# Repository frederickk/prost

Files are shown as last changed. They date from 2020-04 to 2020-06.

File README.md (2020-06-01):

# 🍻 Prost!

v.0.1.2

### Prost! uses Arduino Pro Micros as intermediary to allow Midi host to Midi host communication.

<sub>(Pros + Host) x 2 = [Prost!](https://dictionary.cambridge.org/dictionary/german-english/prost) SWDIT?</sub>

Here's a brief [demo video](https://www.youtube.com/watch?v=BwLtm9UBdX8) with [Ableton Live](https://www.ableton.com/), an [Organelle](https://www.critterandguitari.com/organelle), and [Norns/Fates](https://llllllll.co/t/fates-a-diy-norns-dac-board-for-raspberry-pi/). 

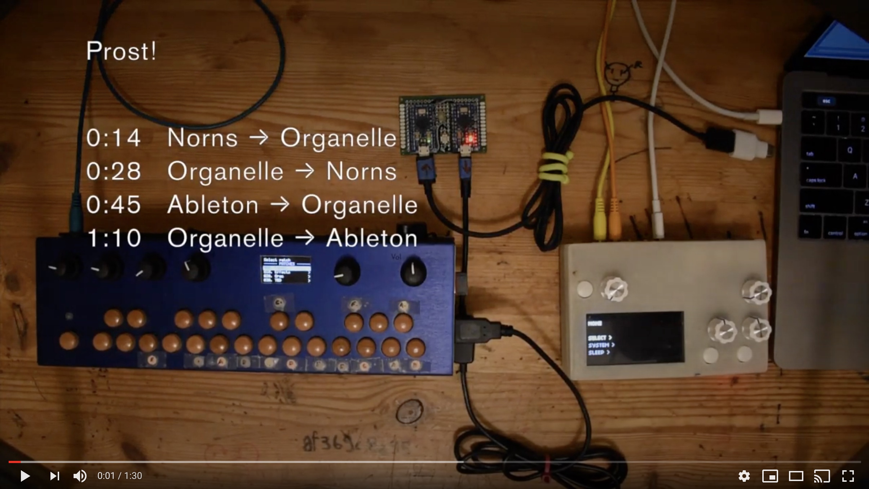
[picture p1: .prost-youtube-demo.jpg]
Prost! video demo (https://www.youtube.com/watch?v=BwLtm9UBdX8&feature=youtu.be)


------
## 💾 Firmware

**Download**

```bash 
$ git clone https://github.com/frederickk/prost.git
```

**Dependencies**

Prost! requires 2 dependencies to build and upload. 

- Install [PlatformIO](https://platformio.org/platformio-ide) this is required to build and flash the Arduinos. You can either install the [CLI](https://platformio.org/install/cli) or the [IDE](https://platformio.org/platformio-ide).
- [USBMIDI](https://github.com/BlokasLabs/usbmidi/) is required for transmitting Midi data over USB, fortunately PlatformIO makes dependency bundling easy.

Before building and flashing be sure to install dependencies.

```bash
  # Install dependencies
  pio lib --storage-dir ./lib install 5841   
```

**Build and Flash**

For 5V / 16MHz boards use:

```bash
  # Build and flash firmware
  pio run -e sparkfun_promicro16 -t upload
```

If using 3.3V / 8MHz boards use:

```bash
  # Build and flash firmware
  pio run -e sparkfun_promicro8 -t upload
```

Be sure to flash both boards 😃.

------
## 🎛️ Hardware

Prost! uses 2 [Pro Micro](https://www.sparkfun.com/products/12587) boards (or any compatible board or clone with an [Atmel 32u4 chip](https://www.amazon.com/s?k=32U4&i=electronics&ref=nb_sb_noss_2)) connected serially (TX/RX) in order to pass USBMidi data. Other boards may work (e.g. Teensy), but I only tested with Pro Micros.

I've created a PCB which reduces the footprint of the device to be only slightly larger than a Pro Micro board itself (38mm x 35mm / 1.25" x 1.375"). Below I've soldered 2 header pins in order to test different boards, but you could solder the boards directly to further reduce the overall thickness (unless you opt to solder on the 3.5mm analog sync jack).

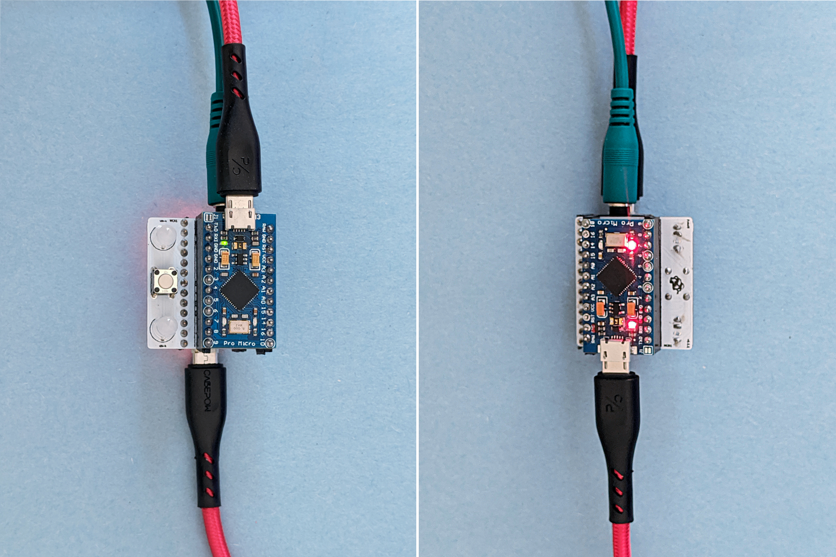
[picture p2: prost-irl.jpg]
Prost! IRL


**Board**

A custom PCB is also available. if there's enough interest I would be willing to produce these in bulk and sell either bare PCB's or populated with components. For now you can order them yourself from [JLCPCB](https://jlcpcb.com/quote/gerberview/d1965d72-c9b5-4de7-8c59-df7167853c5e_1_0_6_0_0.html).

Although, the board is designed first and foremost for Pro Micros it can accomodate a number of other boards. Be mindful to align the marked `TX` and `RX` pins on the Prost! PCB with those on your board. 

| Board | RX | TX | Voltage | Notes |
| --- | -- | -- | --- | ----- |
| [Pro Micro](https://learn.sparkfun.com/tutorials/pro-micro--fio-v3-hookup-guide/hardware-overview-pro-micro) | 0  | 1  | 3.3 or 5 | |
| [Teensy 1.0, ++](https://www.pjrc.com/teensy/td_uart.html) | 2  | 3  | 3.3 or 5 | |
| [Teensy LC, 3.0, 3.1, 3.2, 3.5, 3.6, 4.0](https://www.pjrc.com/teensy/td_uart.html)  | 0  | 1  | 3.3 or 5 | |
| [Arduino Micro](https://content.arduino.cc/assets/Pinout-Micro_latest.pdf) | 20 | 21 | 3.3 or 5 | |
| [Adafruit Feather 32u4, Bluefruit](https://learn.adafruit.com/adafruit-feather-32u4-basic-proto/pinouts) | 0  | 1  | 3.3 | Board must be mounted upside down |
| [Adafruit ItsyBitsy 32u4](https://learn.adafruit.com/introducting-itsy-bitsy-32u4/pinouts) | 0  | 1  | 3 or 5 |

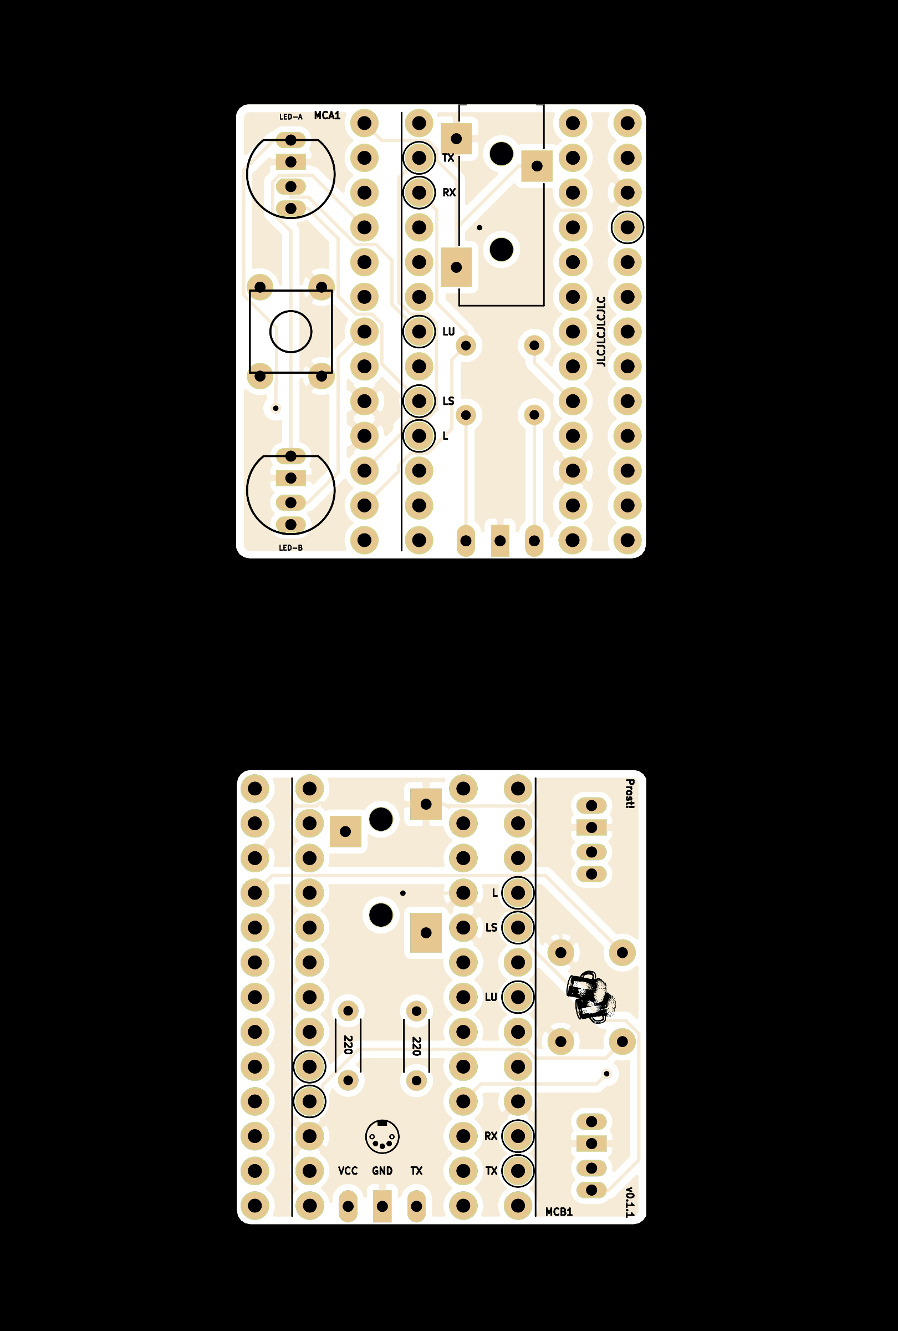
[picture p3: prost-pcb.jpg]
Prost! PCB


**BOM**

| Qty. | Part No. | Item |
| ---- | --- | ---- |
| **2** | | **5V/3.3V [Pro Micro](https://www.sparkfun.com/products/12587)** |
| **1** | **[1825910-6](https://octopart.com/1825910-6-te+connectivity-42270338?r=sp)** | **6mm Momentary push button** |
| 2 | [WP154A4SUREQBFZGW](https://octopart.com/wp154a4sureqbfzgw-kingbright-12087875?r=sp) | 5mm RGB LED (optional) |
| 4 | | 1 x 10 female header (optional) |

Syncing with DIN Midi devices is also possible. Look for the 5-pin Midi graphic on the board and you'll find pin breakouts to connect a 5-pin Midi connector. Be sure to obtain 2 220 ohm resistors as well.

| Qty. | Part No. | Item |
| ---- | --- | ---- |
| 1 | [1134](https://octopart.com/1134-adafruit+industries-32978196?r=sp) | 5-pin MIDI connector (optional) |
| 2 | [220R](https://octopart.com/search?q=220+ohm+resistor&currency=USD&specs=0&category_id=6312) | 220 ohm THT resistors (optional) |

Prost! also supports analog sync, which takes the USB Midi clock signal and converts it to 3.3V or 5V (depending on voltage of Pro Micro) pulse; for Volcas, Pocket Operators, etc. There's room on the board for an [SMD 3.5mm/.125" audio jack](https://octopart.com/search?q=CUI+SJ-3523-SMT&currency=USD&specs=0) or pads to solder a jack type of your choice.

| Qty. | Part No. | Item |
| ---- | --- | ---- |
| 1 | [CUI SJ-3523-SMT](https://octopart.com/search?q=CUI+SJ-3523-SMT&currency=USD&specs=0) | SMD 3.54mm/.125" audio jack (optional) |

**Wiring**

The diagram below shows how to connect the the 2 Pro Micros TX and RX pins. A push button is wired to [reset the bootloader](https://learn.sparkfun.com/tutorials/pro-micro--fio-v3-hookup-guide/all#ts-reset) (for flashing if/as needed). The optional LEDs signal when Midi and Serial commands are being received and sent.

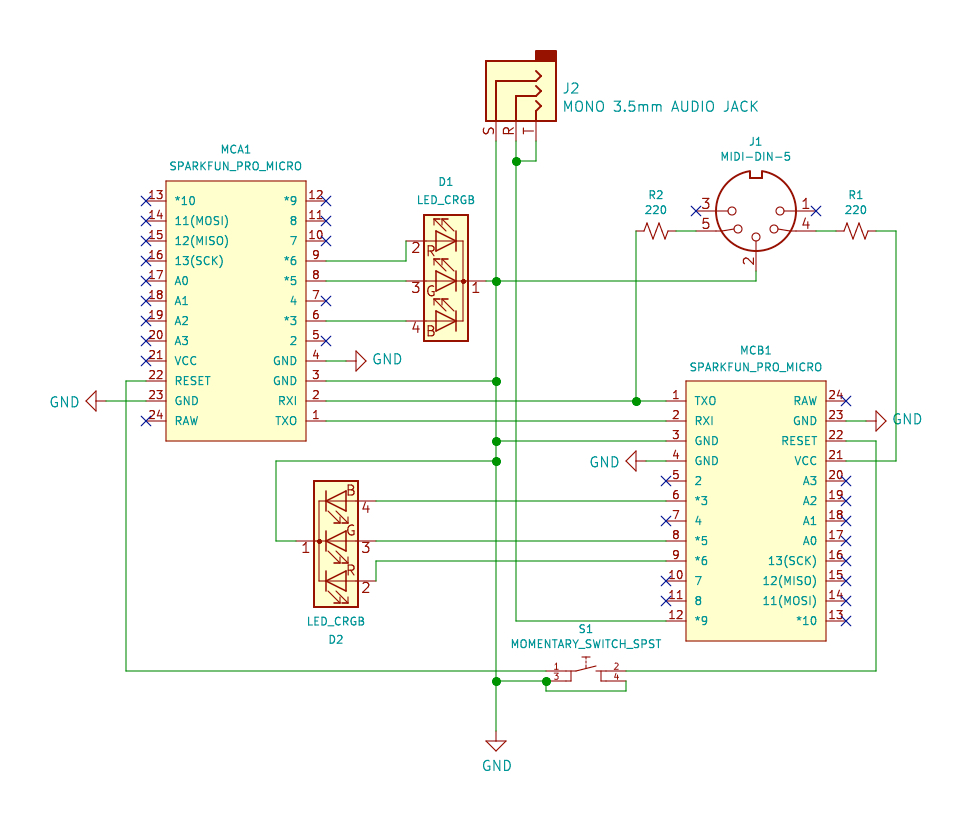
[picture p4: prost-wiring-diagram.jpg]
Prost! PCB


------
## 📜 License

[MIT](https://opensource.org/licenses/MIT)

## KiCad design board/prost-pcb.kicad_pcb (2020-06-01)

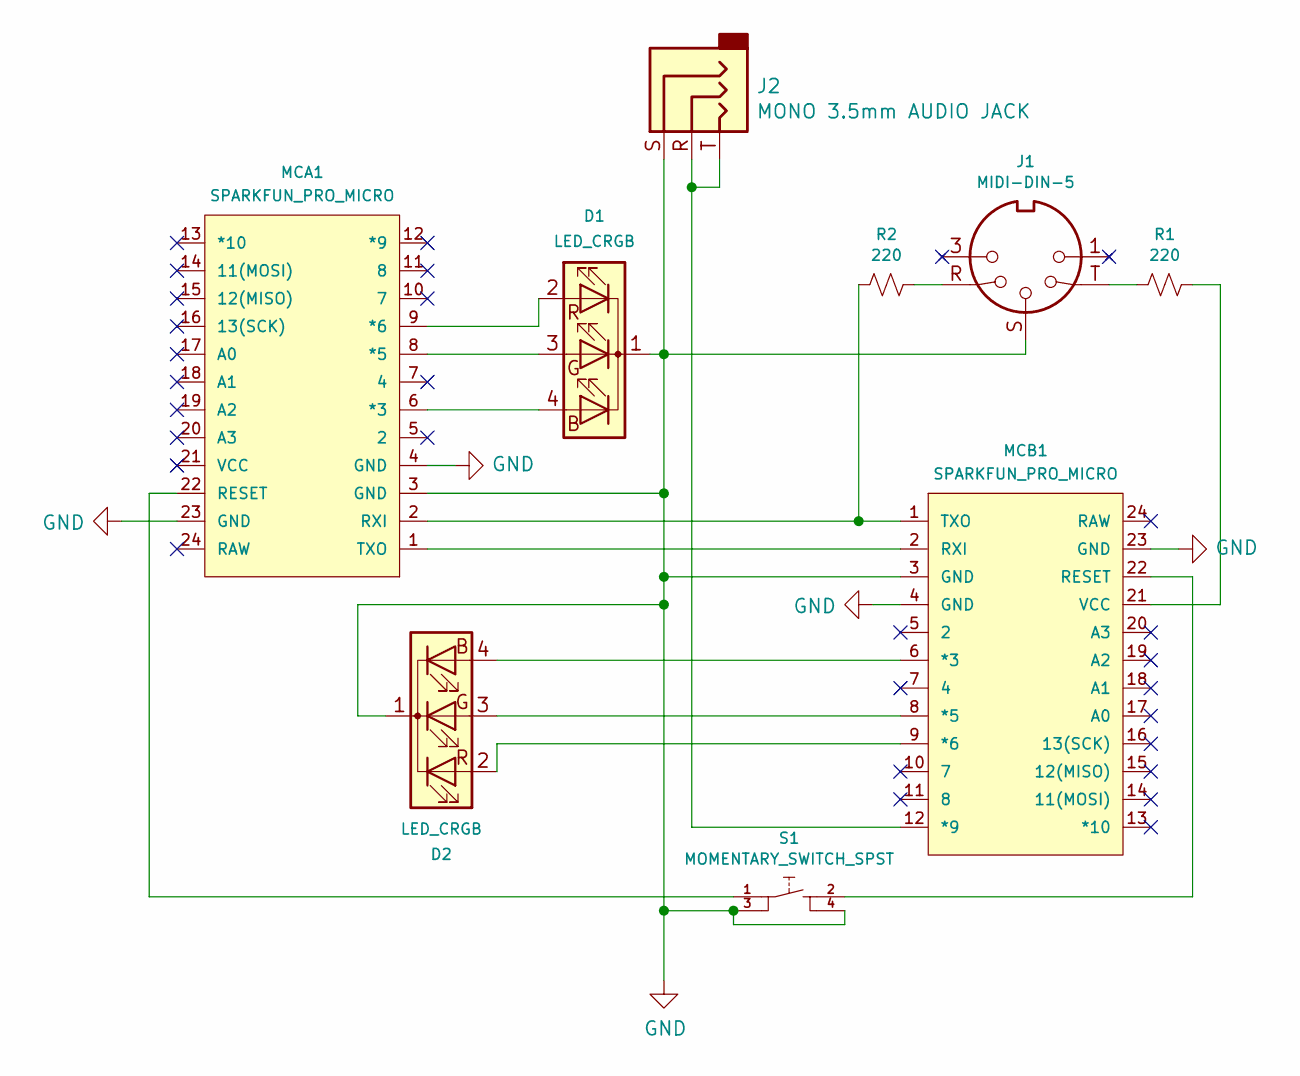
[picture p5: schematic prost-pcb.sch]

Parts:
D1, D2: LED_CRGB; LED_5MM_RGB
J1: MIDI-DIN-5; Jack_3.5mm_CUI_SJ-3523-SMT_Horizontal
J2: MONO 3.5mm AUDIO JACK; Jack_3.5mm_CUI_SJ-3523-SMT_Horizontal
MCA1: SPARKFUN_PRO_MICRO
MCB1: SPARKFUN_PRO_MICRO
R1, R2: 220; R_Axial_DIN0204_L3.6mm_D1.6mm_P5.08mm_Horizontal
S1: MOMENTARY_SWITCH_SPST; MINI_PUSHBUTTON_SWITCH

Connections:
GND: D1.1 (K), D2.1 (K), J1.S, J2.S, MCA1.3 (GND), MCA1.4 (GND), MCA1.23 (GND), MCB1.3 (GND), MCB1.4 (GND), MCB1.23 (GND), S1.3, S1.4
unnamed: D1.2 (RA), MCA1.9 (*6)
unnamed: D1.3 (GA), MCA1.8 (*5)
unnamed: D1.4 (BA), MCA1.6 (*3)
unnamed: D2.2 (RA), MCB1.9 (*6)
unnamed: D2.3 (GA), MCB1.8 (*5)
unnamed: D2.4 (BA), MCB1.6 (*3)
unnamed: J1.R, R2.1
unnamed: J1.T, R1.2
unnamed: J2.R, J2.T, MCB1.12 (*9)
unnamed: MCA1.1 (TXO), MCB1.2 (RXI)
unnamed: MCA1.2 (RXI), MCB1.1 (TXO), R2.2
unnamed: MCA1.22 (RESET), S1.1
unnamed: MCB1.21 (VCC), R1.1
unnamed: MCB1.22 (RESET), S1.2

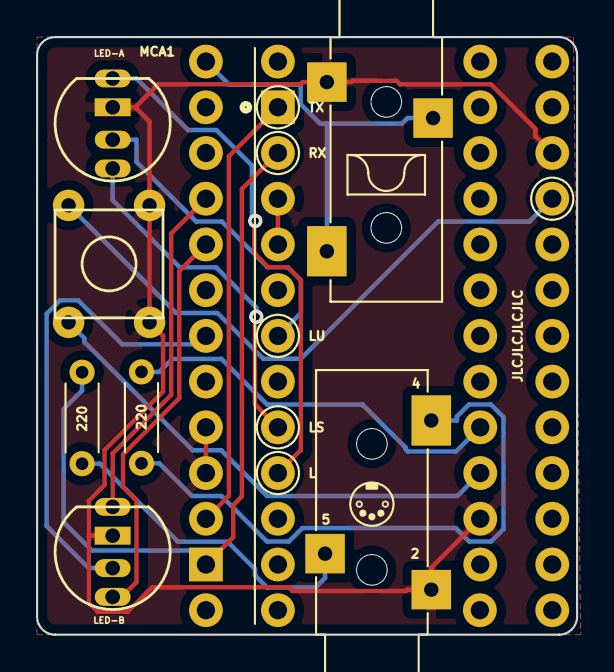
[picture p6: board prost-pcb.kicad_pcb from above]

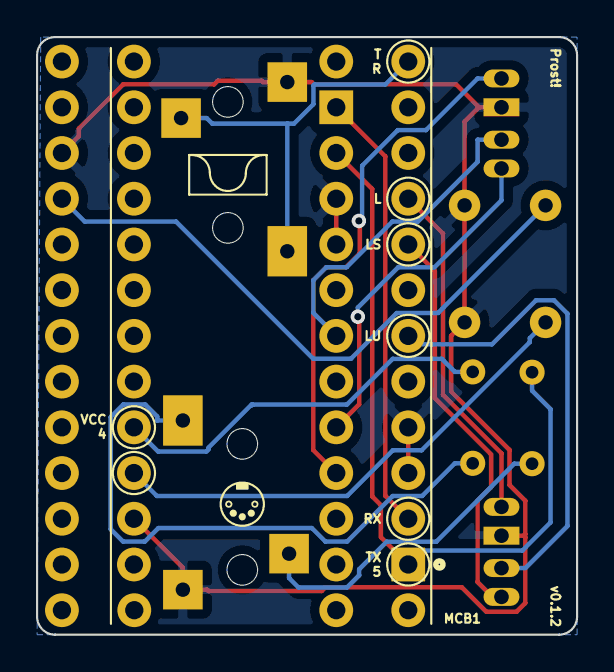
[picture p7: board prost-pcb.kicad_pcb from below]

Board: 2 copper layers, 30.0 x 33.2 mm, 13 parts (3 on the bottom side), 15 nets.

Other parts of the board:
DRILL1: DRILL1
DRILL2: DRILL2
DRILL3: DRILL3
DRILL4: DRILL4

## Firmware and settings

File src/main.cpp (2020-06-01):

/**
 * 🍻 Prost 
 * v.0.1.2
 * 
 * Brings 2 Midi host devices to the table of data sharing.
 * Intermediary device to allow Midi host to Midi host communication.
 * 
 * https://github.com/frederickk/prost
 */
  
#include <Arduino.h>
#include <midi_serialization.h>
#include <midi_messages.h>
#include <usbmidi.h>


#define DEBUG 0 // Set to 1 to see debug log messages.

#if defined(__AVR_ATmega32U4__)
  #ifdef ARDUINO_MICRO
    #define LED_USB D3
    #define LED_SERIAL D5
    #define ANALOG_SYNC D9
  #elif FEATHER_32U4
    #define LED_USB A5
    #define LED_SERIAL A3
    #define ANALOG_SYNC NULL
  #elif CORE_TEENSY
    // TODO(frederickk): Add Teensy pins.
  #else
    #define LED_USB 3
    #define LED_SERIAL 5
    #define ANALOG_SYNC 9
  #endif
#else
  #error Only 32u4 based boards are supported
#endif

#define CLOCK 0xF8
#define START 0xFA
#define CONTINUE 0xFB
#define STOP 0xFC


MidiToUsb midiDataParser;

static uint8_t countClock; // Keep track of clock ticks.
static uint8_t intervalClock = 24; // Default interval is quarter notes.
static uint8_t syncPulse = 0;

void clockHandler(uint8_t byte);
void printClockDebug();


void setup() {
  Serial.begin(9600);
  Serial1.begin(31250); // MIDI baudrate.

  pinMode(LED_USB, OUTPUT);
  pinMode(LED_SERIAL, OUTPUT);
  pinMode(ANALOG_SYNC, OUTPUT); // Analog sync is more reliable with 5V boards.
}

void loop() {
  USBMIDI.poll();

  // When Serial Midi data is received, pass to MidiUSB.
  while(Serial1.available() > 0) {
    uint8_t serialData = Serial1.read();

    USBMIDI.write(serialData);
    USBMIDI.flush();

    digitalWrite(LED_SERIAL, HIGH);
    clockHandler(serialData);
  }
  
  // When MidiUSB data is received, pass to Serial Midi.
  while(USBMIDI.available()) {
    uint8_t usbData = USBMIDI.read();
    midi_event_t event;

    Serial1.write(usbData);
    Serial1.flush();

    if (midiDataParser.process(usbData, event)) {
      digitalWrite(LED_USB, HIGH);
      clockHandler(event.m_data[0]);
    }
  }

  digitalWrite(ANALOG_SYNC, LOW);

  if (syncPulse == 1) {
    digitalWrite(ANALOG_SYNC, HIGH);
    digitalWrite(LED_SERIAL, HIGH);
    digitalWrite(LED_USB, HIGH);
  }

  digitalWrite(LED_USB, LOW);
  digitalWrite(LED_SERIAL, LOW);
}

/**
 * Handles clock Midi messages for analog sync.
 * @param  byte  Incoming Midi byte, following header byte.
 */ 
void clockHandler(uint8_t byte) {
  switch (byte) {
    case CLOCK:
      ++countClock;
      if (countClock == intervalClock) {
        countClock = 0;
        syncPulse = 1;
      } else {
        syncPulse = 0;
      }
#if DEBUG
        Serial.print("---> CLOCK <---");
        printClockDebug();
#endif
      break;
    case START:
      countClock = 0;
      syncPulse = 1;
#if DEBUG
        Serial.println("|--- START ---|");
        printClockDebug();
#endif
      break;
    case CONTINUE:
      syncPulse = 1;
#if DEBUG
        Serial.print("<--- CONT. --->");
        printClockDebug();
#endif
      break;
    case STOP:
      syncPulse = 0;
      countClock = 0;
#if DEBUG
        Serial.print("|-|- STOP  -|-|");
        printClockDebug();
#endif
      break;
  }
}

/**
 * Prints clock debug messages to Serial terminal.
 */ 
void printClockDebug() {
  Serial.print("\t");
  Serial.print(intervalClock);
  Serial.print("\t");
  Serial.print(countClock);
  Serial.print("\t");
  Serial.println(syncPulse);
}
